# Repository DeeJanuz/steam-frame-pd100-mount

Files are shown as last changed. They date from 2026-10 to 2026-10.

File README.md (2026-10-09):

# Steam Frame PD100 Mount

3D-printable mounts that hold a BoboVR PD100 (the PD100 dock with a B100 battery) on the rear battery pod of a Valve Steam Frame. Each mount slides onto a dovetail key on a clip that wraps around the pod and leaves room for the rear cushion:

- **Under mount:** hangs the PD100 below and behind the pod. It suits fast-paced games, since there is less movement low on the head.
- **Over mount:** lays the PD100 over the top of the pod at a flat angle. Very little sticks out behind your head, so you can lean back against a headrest.

| Under mount | Over mount |
|---|---|
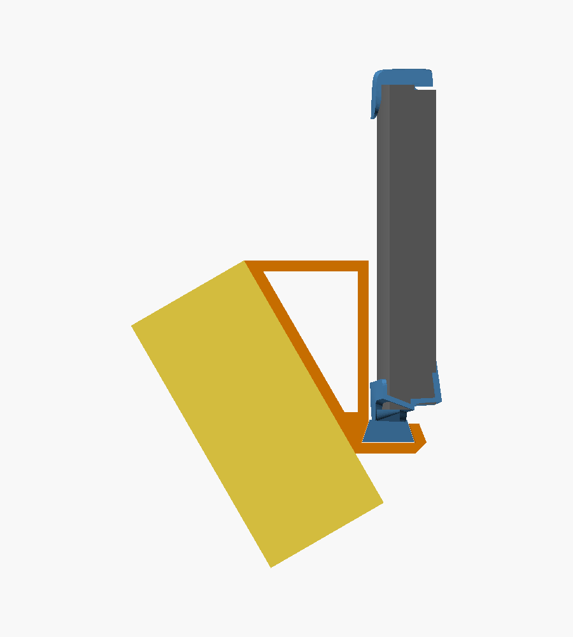
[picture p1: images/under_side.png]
Under mount, section through the middle of the pod with the head to the right
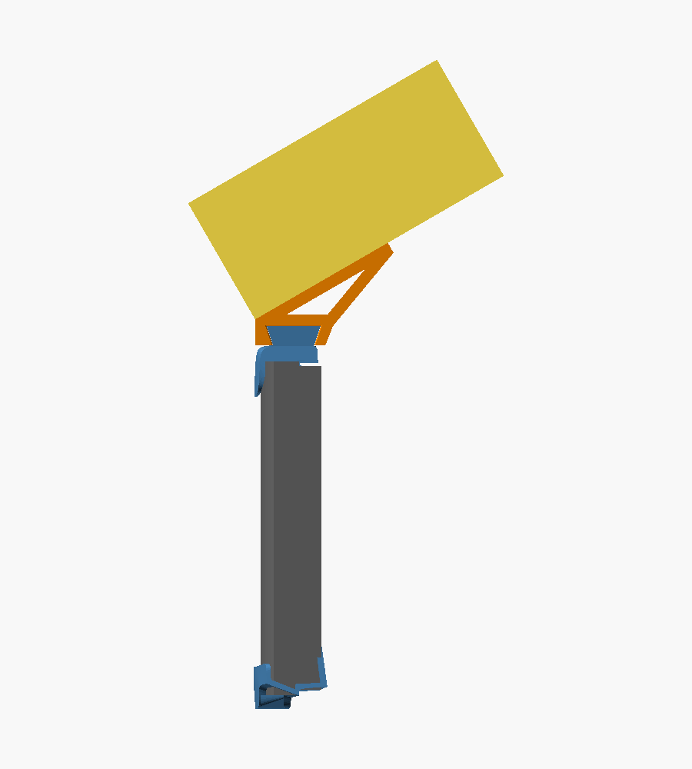
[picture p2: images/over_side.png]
Over mount, section through the middle of the pod with the head to the right
|  |  |

Sections through the middle of the pod, with the head to the right. The pod is gray, the clip is blue, the mount is orange, and the PD100 is shown as a yellow block. The clip is drawn as printed, so its spine overlaps the pod.

## How the clip works

The clip is a remix of [SpanishPotato's Steam Frame back clip](https://www.patreon.com/SpanishPotato/posts/steam-frame-back-171534740), whose file is in `cad/ref/SteamFrameBackClip.stl`. Only its attachment is changed: its two slots are filled in, and our 30 mm dovetail key takes the place of one of them. Everything else is as in that file:

- A cap with a long lip hooks over the pod's top edge.
- A thin spine runs down the side of the pod that faces your head. It has two windows, and a slit under the cap lets it flex.
- At the bottom, a block with a short lip hooks only the outer shell's bottom edge. Legs at the clip's ends join it to the spine. In the middle, the head side of the pod's bottom edge stays free, so the rear cushion can go back on.
- Three small pegs face the pod from the spine and legs.

There are four versions. `clip_over` has the key on top of the cap for the over mount, and `clip_under` has it under the bottom block for the under mount. Each mount slides onto its key from the side.

The other two are versions of `clip_over` with a different outline, for an over mount that rocks less. Seen from the head side, the original is a trapezoid: about 32 mm wide at the cap and 59 mm wide at the bottom. Both versions have a cap 59 to 60 mm wide and a 55 mm key, the full width of the over mount. At every height, the cross-section is the same as the original's, so the cap, lips, slit, and bottom block grip the pod in the same way. `cad/ref/reshape.py` makes these changes.

- `clip_over_straight` is 59 mm wide from top to bottom. Its bottom is the original's, so the cushion fits the same way as with `clip_over`.
- `clip_over_wide` is the original turned upside down: 60 mm wide at the cap and about 32 mm at the bottom. The narrow bottom brings the legs and end bars in to about 10 to 16 mm from the middle. In `clip_over`, that part of the pod's bottom edge on the head side stays free for the cushion, so the cushion may not go back on with `clip_over_wide`. The two small pegs at the bottom also move in, from about 22 mm to 13 mm out.

## What you need

- A Valve Steam Frame.
- A [BoboVR PD100 charging dock](https://www.amazon.com/dp/B0FLXQMPCS). This listing is the dock only, without a battery.
- A B100-style battery for the dock, such as this [DMMNS 10000 mAh two-pack](https://www.amazon.com/dp/B0FHK169RV), which is sold as a replacement for the BoboVR B100.
- 3M Command strips to hold the PD100 on the mount.

## Parts

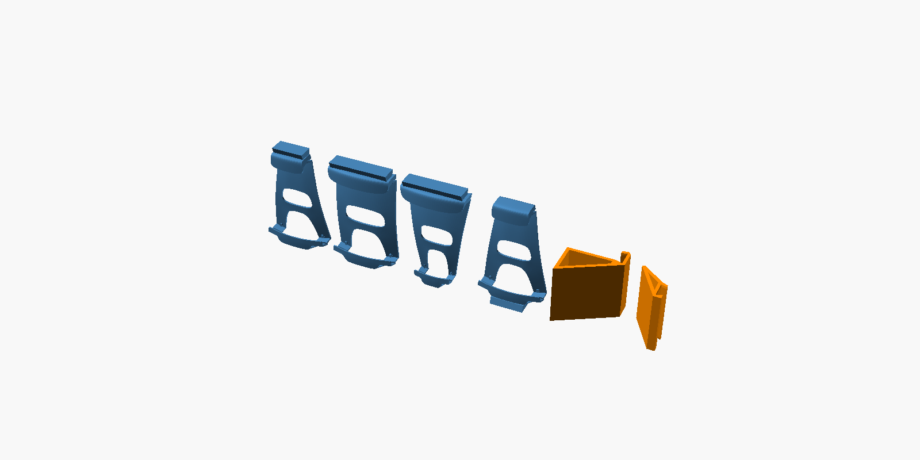
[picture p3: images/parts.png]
The four clips and both mounts, as they sit on the print bed


| File | Quantity | Notes |
|---|---|---|
| `stl/clip_under.stl` | 1 | Clip with the key underneath, for the under setup |
| `stl/clip_over.stl` | 1 | Clip with the key on top, for the over setup |
| `stl/clip_over_straight.stl` | 1 | Instead of `clip_over`: 59 mm wide at the top and bottom, so the over mount rocks less |
| `stl/clip_over_wide.stl` | 1 | Instead of `clip_over`: wide at the top and narrow at the bottom, so the over mount rocks less |
| `stl/under_mount.stl` | 1 | For the under setup |
| `stl/over_mount.stl` | 1 | For the over setup |

Print the clip and mount for the setup you want, or both pairs.

## Printing

- The STL files are already oriented.
- The clips print upright like the original file, 100 mm tall: `clip_over`, `clip_over_straight`, and `clip_over_wide` stand on the bottom block and `clip_under` on its key. `clip_over_wide` stands on a block only about 15 mm wide under a 60 mm cap, so use a brim. They need supports under the end bars at the bottom, under the tip of the long lip, and under the cap. If supports end up in the slit under the cap, clear them out completely, since the spine flexes there.
- The mounts print on their side with no supports, 55 mm tall, so the layers run in the direction that carries the battery's weight.
- PETG is recommended. PLA can soften over time from body heat and a warm battery.
- As solid plastic, `clip_over` and `clip_under` are about 11.5 cm³ each, `clip_over_wide` about 15 cm³, `clip_over_straight` about 17 cm³, the under mount about 26 cm³, and the over mount about 14 cm³. Your slicer will report the actual weight for your infill.

## Assembly

### Fitting the clip

1. With the spine against the side of the pod that faces your head, hook the cap's long lip over the pod's top edge.
2. Press the bottom of the clip toward the pod until the short lip snaps over the outer shell's bottom edge.
3. Center the clip on the pod.

### Under setup

1. Fit `clip_under`.
2. Slide the under mount onto the key under the clip from one side until it is centered. Its upper part sits just behind the pod's outer shell.
3. Stick the PD100 to the mount's angled face with 3M Command strips. The PD100's flat bottom goes against the mount, with the display edge toward the pod.

### Over setup

1. Fit `clip_over`, `clip_over_straight`, or `clip_over_wide`.
2. Slide the over mount onto the key on top of the clip from one side until it is centered. On `clip_over_straight` and `clip_over_wide`, the key runs the mount's full width.
3. Stick the PD100 to the platform with Command strips, with its display edge at the back of the platform.

The dovetail fit is tight on purpose so the mount stays put by friction. If a mount will not slide on, lightly sand the sides of the key, or increase `dt_gap` in `cad/common.scad` and reprint the mount.

## Fit and customizing

The clip's fit is the original file's and has not been changed. The pod measurements come from calipers on one Steam Frame and place the mounts and the assembly views. The main numbers:

- The pod's outer shell is 87.0 mm tall at the seam, and the part that faces your head is 84.5 mm tall.
- The pod is 12.0 mm thick at the middle of its top and bottom edges, and the outer shell is about 6.5 mm of that.
- The outer shell bulges about 1.6 mm at mid-height.
- Seen from above, the pod curves with a radius of about 117.5 mm.

The design is written in OpenSCAD. Settings you are most likely to change:

| File | Setting | What it does |
|---|---|---|
| `cad/pod_dims.scad` | all values | Pod measurements |
| `cad/common.scad` | `curve_radius` | Curve of the pod seen from above |
| `cad/common.scad` | `dt_gap` | Dovetail clearance per face |
| `cad/common.scad` | `mount_width` | Mount width (55 mm by default) |
| `cad/common.scad` | `key_len` | Length of the key on `clip_over` and `clip_under` (30 mm by default) |
| `cad/common.scad` | `key_len_wide` | Length of the key on `clip_over_straight` and `clip_over_wide` (the mount's width by default) |
| `cad/under.scad` | `under_tilt` | Angle of the under mount's face, from vertical (30 by default) |
| `cad/under.scad` | `corner_below` | How far below the pod the PD100's front corner may reach. This is the part that can touch your neck when you look up. |
| `cad/over.scad` | `over_tilt` | Angle of the over mount's platform, from vertical (60 by default) |
| `cad/over.scad` | `platform_len` | Platform length from its back end to the tip (40 mm by default) |
| `cad/over.scad` | `back_reach` | Moves the PD100 back and down along the platform, away from your head (0 by default) |

## Building the STL files

Use a recent OpenSCAD development snapshot. From the repository folder:

```sh
openscad -D 'part="clip_under"'  -D print=true -o stl/clip_under.stl  cad/clip.scad
openscad -D 'part="clip_over"'   -D print=true -o stl/clip_over.stl   cad/clip.scad
openscad -D 'part="clip_over_straight"' -D print=true -o stl/clip_over_straight.stl cad/clip.scad
openscad -D 'part="clip_over_wide"' -D print=true -o stl/clip_over_wide.stl cad/clip.scad
openscad -D 'part="under_mount"' -D print=true -o stl/under_mount.stl cad/under.scad
openscad -D 'part="over_mount"'  -D print=true -o stl/over_mount.stl  cad/over.scad
```

`clip_over_straight` and `clip_over_wide` are built from `cad/ref/SteamFrameBackClip_straight.stl` and `cad/ref/SteamFrameBackClip_wide_top.stl`. Those files only need rebuilding if you change how the original's slots are filled or the pod's curve. Rebuilding them takes Python with numpy, trimesh, and manifold3d:

```sh
openscad -D 'part="clip_filled"' -o /tmp/clip_filled.stl cad/clip.scad
python cad/ref/reshape.py straight /tmp/clip_filled.stl cad/ref/SteamFrameBackClip_straight.stl
python cad/ref/reshape.py wide_top /tmp/clip_filled.stl cad/ref/SteamFrameBackClip_wide_top.stl
```

Opening `cad/under.scad` or `cad/over.scad` in OpenSCAD without any settings shows the assembly with the pod and a block the size of the PD100. Opening `cad/clip.scad` shows the clip on the pod with both keys.

## Disclaimer

This project is not affiliated with Valve or BoboVR. It holds a lithium battery on your head, so check the fit and the Command strips before each session, and stop using it if anything cracks or loosens.

## License

MIT. See [LICENSE](LICENSE). The MIT license does not cover SpanishPotato's clip: `cad/ref/SteamFrameBackClip.stl`, `cad/ref/SteamFrameBackClip_straight.stl`, `cad/ref/SteamFrameBackClip_wide_top.stl`, and the clip STLs built from them (`stl/clip_over.stl`, `stl/clip_over_straight.stl`, `stl/clip_over_wide.stl`, and `stl/clip_under.stl`). See the [original post](https://www.patreon.com/SpanishPotato/posts/steam-frame-back-171534740) for its terms.

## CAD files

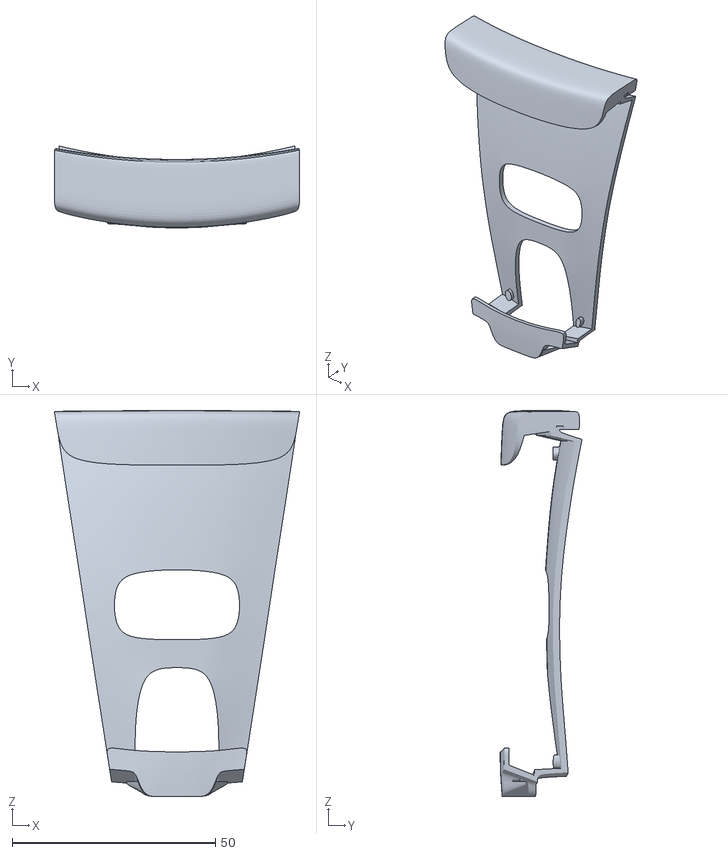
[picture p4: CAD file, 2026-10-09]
cad/ref/SteamFrameBackClip_wide_top.stl
60.4 x 20.2 x 95.1

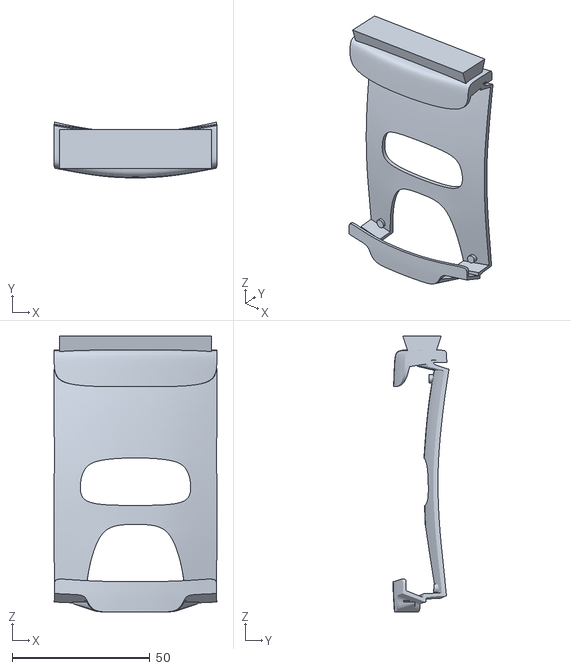
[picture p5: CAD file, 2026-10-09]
stl/clip_over_straight.stl
59.0 x 20.3 x 100.0

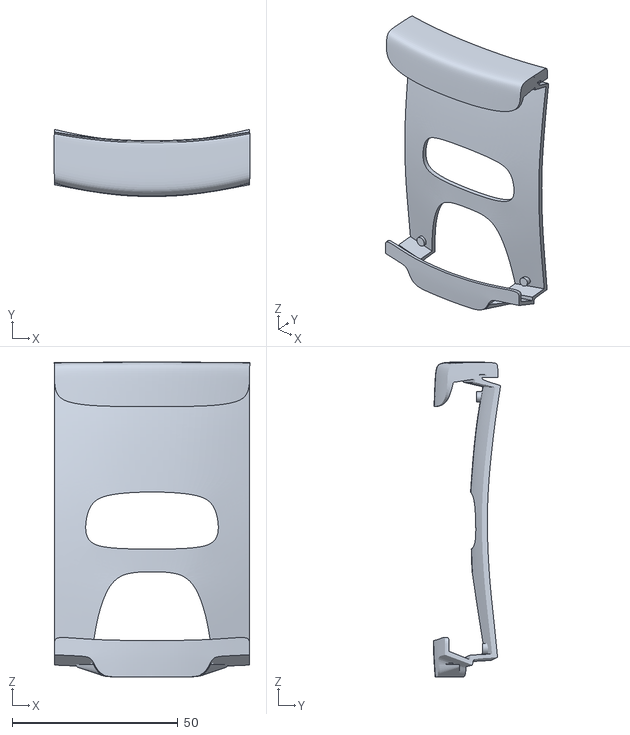
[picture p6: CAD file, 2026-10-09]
cad/ref/SteamFrameBackClip_straight.stl
59.0 x 20.3 x 95.1

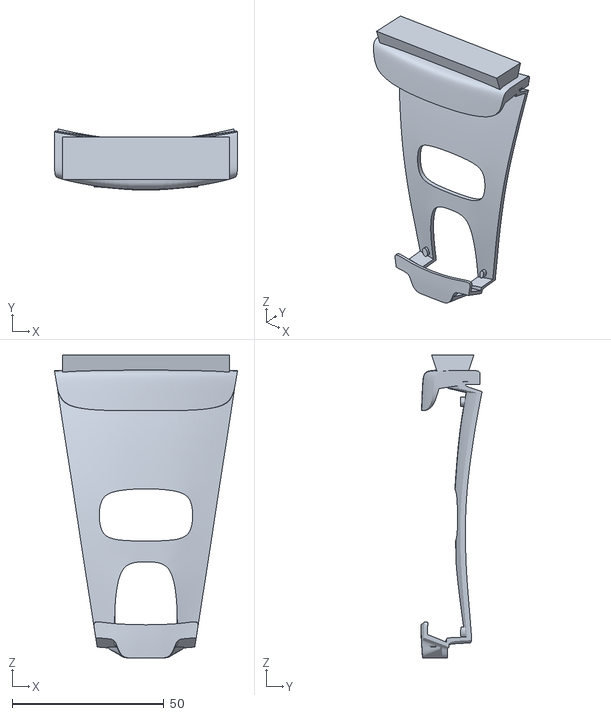
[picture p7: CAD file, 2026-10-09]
stl/clip_over_wide.stl
60.4 x 20.2 x 100.0

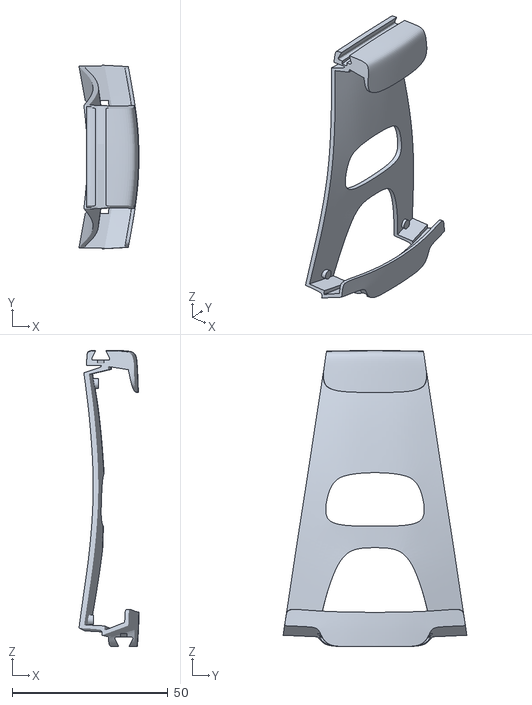
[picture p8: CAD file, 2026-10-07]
cad/ref/SteamFrameBackClip.stl
19.3 x 59.0 x 95.1

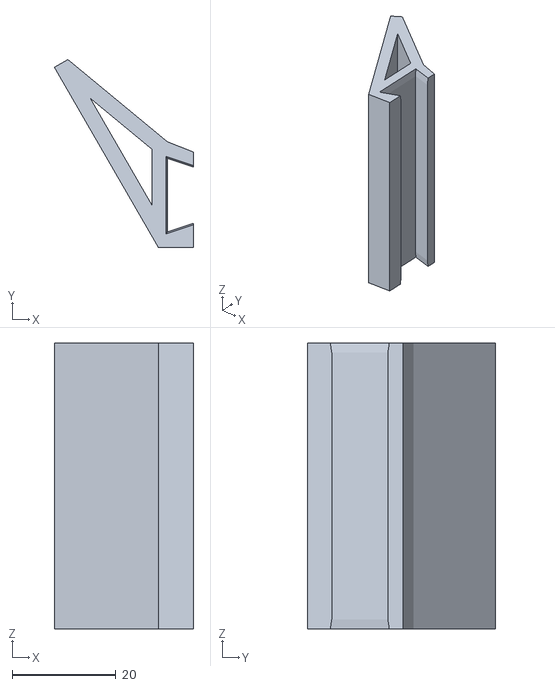
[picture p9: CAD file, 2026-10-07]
stl/over_mount.stl
26.8 x 36.1 x 55.0

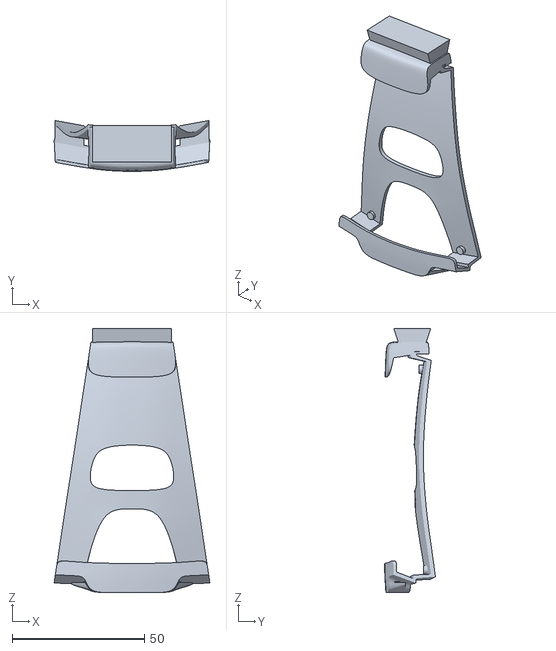
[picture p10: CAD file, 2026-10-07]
stl/clip_over.stl
59.0 x 19.3 x 100.0

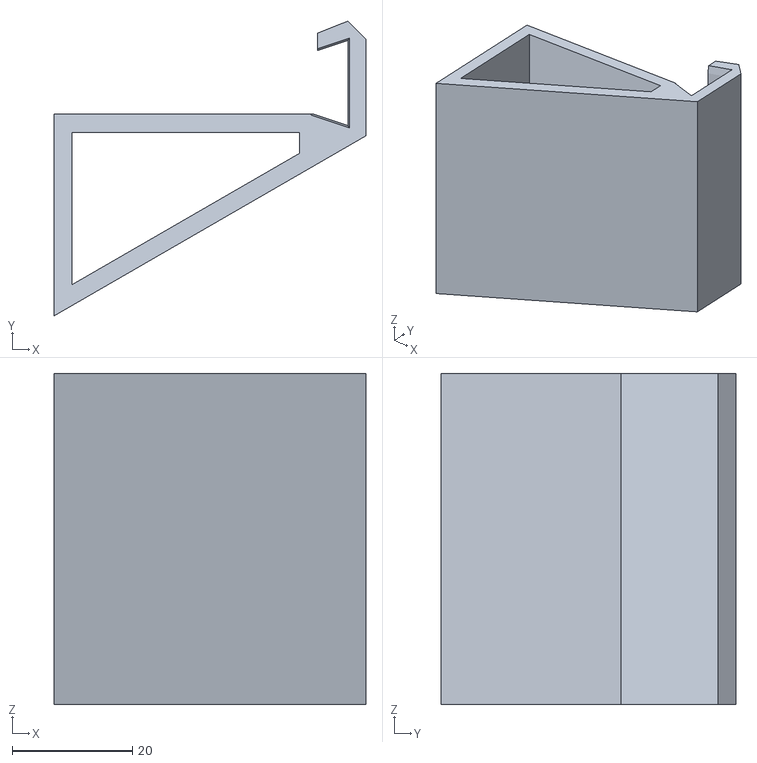
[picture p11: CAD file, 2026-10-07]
stl/under_mount.stl
51.8 x 49.0 x 55.0

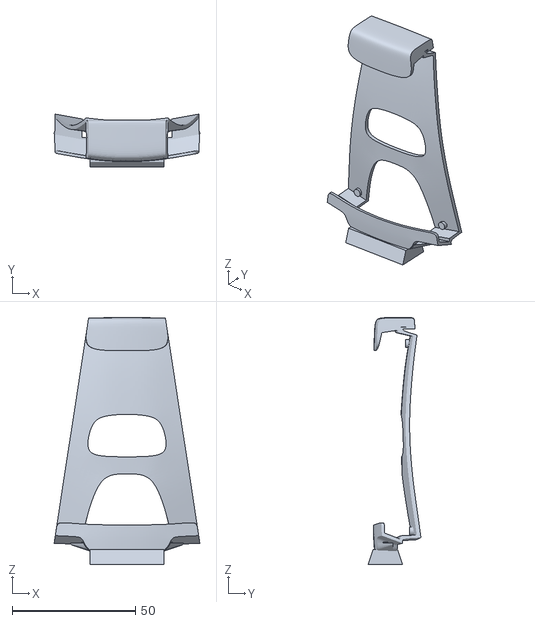
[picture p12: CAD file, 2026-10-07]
stl/clip_under.stl
59.0 x 21.4 x 100.1

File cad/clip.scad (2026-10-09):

// The clip that holds either mount on the Steam Frame's battery pod. It is
// SpanishPotato's Steam Frame back clip
// (https://www.patreon.com/SpanishPotato/posts/steam-frame-back-171534740)
// with its two slots filled and our dovetail key added in place of one of
// them: on top of the cap for the over mount, or under the bottom block for
// the under mount. Everything else is the original: the cap and its long lip
// over the pod's top edge, the slit under the cap that lets the spine flex,
// the spine on the head side with its two windows, the pegs, and the bottom
// block and short lip, which leave the head side of the pod's bottom edge
// free for the cushion. ref/SteamFrameBackClip.stl is that file merged into
// one solid. Not covered by this project's MIT license. Axes as in
// pod_dims.scad.
include <common.scad>

part = "clip_assembly";  // clip_assembly, clip_over, clip_under, clip_over_wide, clip_over_straight

// clip_over has only the key on top, for the over mount; clip_under has only
// the key underneath, for the under mount. Both print upright like the
// original, standing on the bottom block or the bottom key.
// key_bot[1] is the height of the bottom block's underside.
if (part == "clip_over") translate([0, 0, print ? -key_bot[1] : 0]) clip(bottom = false);
if (part == "clip_under") translate([0, 0, print ? dt_height - key_bot[1] : 0]) clip(top = false);
// clip_over_wide and clip_over_straight have a cap as wide as the original's
// bottom and a 55 mm key, so the over mount rocks less (see ref/reshape.py).
// clip_over_wide is clip_over upside down in outline: its bottom is as narrow
// as the original's cap, so its legs come in over the middle of the pod's
// bottom edge, where clip_over leaves room for the cushion. clip_over_straight
// keeps the original's bottom.
if (part == "clip_over_wide") translate([0, 0, print ? -key_bot[1] : 0]) clip_reshaped(clip_wide_file);
if (part == "clip_over_straight") translate([0, 0, print ? -key_bot[1] : 0]) clip_reshaped(clip_straight_file);
// Both slots filled and no key: the input to ref/reshape.py.
if (part == "clip_filled") clip(top = false, bottom = false);
if (part == "clip_assembly") {
    color("dimgray") pod();
    color("steelblue") clip();
}

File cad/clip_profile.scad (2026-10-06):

// Cross-section of the clip, in the (Y, Z) plane; see pod_dims.scad.
// The clip wraps the whole pod: a thin spine lies on the head-side face, bars
// cross the top and bottom edges, and short lips reach over the outer face.
// Each bar steps down behind the outer shell's rim to fill the ledge at the seam.
//
// As printed, the spine bows toward the pod, which splays the bars open so
// the lips pass over the pod's edges. On the pod, the head-side face presses
// the spine flat. That closes the bars and keeps the lips pressed on the
// outer face, so the clip does not rattle.
include <pod_dims.scad>

spine_gap     = 0.2;    // spine to the head-side face, once pressed flat
spine_thick   = 2.0;
spine_bow     = 3.0;    // as printed, how far the spine bows toward the pod at mid-height
bar_thick     = 3.0;    // over the outer shell's rim
lip_thick     = 1.6;
lip_len       = 4.0;    // how far each lip reaches down the outer face
lip_ramp      = 1.0;    // lead-in at each lip's tip
step_gap_y    = 0.35;   // a bar's step to the back of the outer shell
step_gap_z    = 0.25;   // a bar to the top of the head-side part
inner_chamfer = 1.0;    // inside corner where the spine meets a bar
edge_chamfer  = 1.0;    // outside corners

// Underside of a bar over the outer shell, for a given rim clearance.
function z_bar(clearance) = shell_height / 2 + clearance;
// Outer face, modeled as a parabola from the edges (Y = 0) to the bulge at mid-height.
function outer_y(z) = -outer_bulge * (1 - pow(z / (shell_height / 2), 2));

y_spine_in  = total_thick_edge + spine_gap;
y_spine_out = y_spine_in + spine_thick;
y_step      = max(shell_thick_top, shell_thick_bottom) + step_gap_y;
z_head      = head_part_height / 2 + step_gap_z;

// Where the spine meets a bar. With the spine bowed, each bar turns about this
// point by bow_angle, the slope at the end of the bowed spine.
pivot = [y_spine_in + spine_thick / 2, z_head - inner_chamfer];
function bow_angle(bow) = atan(2 * bow / pivot[1]);

// Back of a lip at its tip, with the spine flat. The lips lean out to follow
// the bulge, so this is the rearmost point of the clip.
function lip_back_y(clearance) = outer_y(z_bar(clearance) - lip_len) - lip_thick;

// Top bar and lip with the spine flat, from the pivot's height up.
module bar_2d(clearance) {
    zr = z_bar(clearance);
    zt = zr + bar_thick;
    z_tip = zr - lip_len;
    y_tip = outer_y(z_tip);
    polygon([[y_spine_in, pivot[1] - 0.3],
             [y_spine_in, z_head - inner_chamfer],
             [y_spine_in - inner_chamfer, z_head],
             [y_step, z_head],
             [y_step, zr],
             [0, zr],
             [y_tip, z_tip + lip_ramp],
             [y_tip - lip_ramp, z_tip],
             [y_tip - lip_thick, z_tip],
             [-lip_thick, zt - edge_chamfer],
             [-lip_thick + edge_chamfer, zt],
             [y_spine_out - edge_chamfer, zt],
             [y_spine_out, zt - edge_chamfer],
             [y_spine_out, pivot[1] - 0.3]]);
}

// Upper half of the spine, bowed into a parabola that is flat at mid-height
// and reaches the pivot at bow_angle. Offsets are normal to the centerline, so
// the end matches the turned bar.
module spine_half_2d(bow) {
    n = 24;
    zp = pivot[1];
    function ctr(z) = pivot[0] - bow * (1 - pow(z / zp, 2));
    function nrm(z) = let(s = 2 * bow * z / (zp * zp)) [1, -s] / sqrt(1 + s * s);
    zs = [for (i = [0 : n]) -0.5 + (zp + 0.3 + 0.5) * i / n];
    polygon(concat([for (z = zs) [ctr(z), z] - spine_thick / 2 * nrm(z)],
                   [for (i = [n : -1 : 0]) [ctr(zs[i]), zs[i]] + spine_thick / 2 * nrm(zs[i])]));
}

// Turn 2D children about the pivot by the bow's angle, opening the bar.
module turn_bar(bow) {
    translate(pivot) rotate(-bow_angle(bow)) translate(-pivot) children();
}

// Top half. The bottom half is this mirrored.
module clip_half_2d(clearance, bow) {
    spine_half_2d(bow);
    turn_bar(bow) bar_2d(clearance);
}

// The clip's cross-section: bowed as printed (bow = spine_bow), or pressed flat
// on the pod (bow = 0).
module clip_2d(clearance, bow) {
    clip_half_2d(clearance, bow);
    mirror([0, 1]) clip_half_2d(clearance, bow);
}

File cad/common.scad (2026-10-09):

// Shared settings and helpers for the Steam Frame PD100 mounts. Every mount
// prints on its side, so the layers lie in the plane that carries the PD100's
// weight. Axes as in pod_dims.scad.
include <pod_dims.scad>

part     = "none";
explode  = 0;          // assembly views: slide the mount out along X
print    = false;      // true: turn the chosen part to its print orientation
pod_view = pod_width;  // assembly views: how much of the pod's width to draw

curve_radius  = 117.5;  // pod's curve seen from above (between the R110 and R125 test gauges)

// BoboVR PD100 combo (dock + B100 battery), from the Amazon listing.
pd_across = 113;  // left to right, same direction as the pod
pd_up     = 75;   // along the mount's face
pd_thick  = 35;

mount_width = 55;
mount_wall  = 3;      // material around the groove in a mount
plate_thick = 3;      // platform thickness at its tip

dt_root    = 10;      // dovetail key width at its base
dt_tip     = 14;      // key width at its top
dt_height  = 5;
dt_gap     = 0.05;    // clearance per face in a mount's groove; starts tight, open up if needed
dt_lead_in = 2;       // groove flares open over this length at each end of a mount

// The clip is ref/SteamFrameBackClip.stl with its two slots replaced by our
// key. In that file X runs through the pod from the head side, Y across it,
// and Z up. These place it on the pod:
clip_file = "ref/SteamFrameBackClip.stl";
clip_mid  = 29.5;    // file Y at the clip's middle
clip_y0   = 17.4;    // file X of the top lip's inner face, which sits on the pod's outer face
clip_z0   = 47.3;    // file Z halfway between the cap and the bottom block, at the seam
clip_back_y = clip_y0 - 19.31;   // rearmost point of the clip: the lips at its middle

// Keys, as [Y of the centerline, Z of the base]: one on top of the cap for the
// over mount and one under the bottom block for the under mount, each where
// the file has its slot. Both run straight along X, key_len long.
key_len = 30;
key_top = [clip_y0 - 8.8,   95.0 - clip_z0];   // points up
key_bot = [clip_y0 - 14.42, 0 - clip_z0];      // points down

// The file's slots, in its (X, Z) plane with some overlap into the walls.
top_slot = [[4.0, 91.3], [10.0, 91.3], [10.0, 95.2], [4.0, 95.2]];
bot_slot = [[11.4, 0.01], [17.4, 0.01], [17.4, 3.7], [11.4, 3.7]];   // stops just above the block's underside, which a fill flush with it would leave non-manifold

// The groove's outer wall leans with the dovetail's flank.
flank_dy = (dt_tip - dt_root) / 2;
// Front of a mount (toward the head) at the key's base and at its tip.
function y_front_base(key) = key[0] + dt_root / 2 + dt_gap + mount_wall * sqrt(1 + (flank_dy / dt_height) ^ 2);
function y_front_tip(key)  = y_front_base(key) + flank_dy;
// Rear of a mount, level with the key's tip.
function y_rear_tip(key)   = key[0] - dt_tip / 2 - dt_gap - mount_wall;

// Extrude a (Y, Z) profile along X, centered.
module extrude_x(len) {
    translate([-len / 2, 0, 0]) rotate([90, 0, 90]) linear_extrude(len) children();
}

// Sweep a (Y, Z) profile along the pod's curve, keeping x_lo <= X <= x_hi.
module swept(x_lo, x_hi) {
    reach = max(abs(x_lo), abs(x_hi)) + 2;
    ang = 2 * asin(min(0.99, reach / (curve_radius - 15)));
    intersection() {
        translate([0, curve_radius, 0]) rotate(-90 - ang / 2)
            rotate_extrude(angle = ang, $fn = 720)
                translate([curve_radius, 0]) mirror([1, 0]) children();
        translate([x_lo, -500, -500]) cube([x_hi - x_lo, 1000, 1000]);
    }
}

// Male dovetail with its base on the X axis, pointing +Y. The base runs 1 mm
// below the axis so it stays buried in the part it stands on.
module rail_2d() {
    polygon([[-dt_root / 2, -1], [dt_root / 2, -1],
             [dt_tip / 2, dt_height], [-dt_tip / 2, dt_height]]);
}

// Matching groove with clearance g on every face, open below the X axis.
module groove_2d(g) {
    offset(delta = g) rail_2d();
    translate([-dt_root / 2 - g, -1]) square([dt_root + 2 * g, 1]);
}

// Place 2D children at point q, rotated so +Y points along dir.
module at(q, dir) {
    translate(q) rotate(atan2(dir[1], dir[0]) - 90) children();
}

// Move children from the clip file's axes onto the pod.
module clip_file_to_pod() {
    rotate([0, 0, -90]) translate([-clip_y0, -clip_mid, -clip_z0]) children();
}

// Fill a slot, given in the file's (X, Z) plane, over the length of the part
// around it: everything in the file inside box, closed up.
module fill_slot(slot, box) {
    intersection() {
        translate([0, 70, 0]) rotate([90, 0, 0]) linear_extrude(80) polygon(slot);
        hull() intersection() {
            import(clip_file);
            translate(box[0]) cube(box[1]);
        }
    }
}

// The clip on the pod, with both slots filled and a key on top of the cap
// (top), under the bottom block (bottom), or both.
module clip(top = true, bottom = true) {
    clip_file_to_pod() {
        import(clip_file);
        fill_slot(top_slot, [[0, 0, 91.3], [20, 60, 5]]);
        fill_slot(bot_slot, [[9, 0, -1], [11, 60, 4.7]]);
    }
    extrude_x(key_len) {
        if (top) at(key_top, [0, 1]) rail_2d();
        if (bottom) at(key_bot, [0, -1]) rail_2d();
    }
}

// The same clip with its outline changed by ref/reshape.py, as seen from the
// head side. wide_top is upside down: as wide at the cap as the original is at
// the bottom, and as narrow at the bottom as the original's cap. straight is
// as wide as the original's bottom all the way up. The files are in pod axes
// with both slots already filled. Their wide caps carry a key as long as the
// mount.
clip_wide_file     = "ref/SteamFrameBackClip_wide_top.stl";
clip_straight_file = "ref/SteamFrameBackClip_straight.stl";
key_len_wide       = mount_width;

module clip_reshaped(file) {
    import(file);
    extrude_x(key_len_wide) at(key_top, [0, 1]) rail_2d();
}

// Extrude a mount's (Y, Z) profile along X and cut the groove for a key at
// [Y, Z of its base] that points up (s = 1) or down (s = -1). The groove
// flares at both ends so the tight fit starts onto the key easily.
module mount_body(key, s) {
    difference() {
        extrude_x(mount_width) difference() {
            children();
            at(key, [0, s]) groove_2d(dt_gap);
        }
        for (m = [0, 1]) mirror([m, 0, 0])
            translate([mount_width / 2 - dt_lead_in, key[0], key[1]]) rotate([90, 0, 90])
                linear_extrude(dt_lead_in + 0.01, scale = 1.06)
                    rotate(s > 0 ? 0 : 180) groove_2d(dt_gap - 0.02);
    }
}

// Pod outline for the assembly views: outer shell and head-side part, swept.
module pod() {
    swept(-pod_view / 2, pod_view / 2) {
        translate([0, -shell_height / 2]) square([shell_thick_top, shell_height]);
        translate([shell_thick_top, -head_part_height / 2])
            square([total_thick_edge - shell_thick_top, head_part_height]);
    }
}

// Lay a part on its side, lowest X face (x_lo) on the bed.
module on_side(x_lo) {
    if (print) translate([0, 0, -x_lo]) rotate([0, -90, 0]) children();
    else children();
}

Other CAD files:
cad/over.scad
cad/pod_dims.scad
cad/under.scad

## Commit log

2026-09-28 Add under and over PD100 mounts for the Steam Frame
    Clip-on arms snap over the Steam Frame's rear battery pod and carry a
    dovetail rail across their backs. Two mounts slide onto those rails:
    - The under mount hangs the BoboVR PD100 below and behind the pod at
    30 degrees, keeping its front corner 25 mm below the pod so it clears
    the neck.
    - The over mount uses the same arms turned upside down and lays the
    PD100 over the top on a 40 mm platform at 60 degrees, so little
    sticks out behind the head.
    Includes the OpenSCAD source, print-ready STLs, and README images.
    [common.scad, hook_profile.scad, over.scad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]
2026-09-28 Remove the assembly image from the README
2026-10-06 Replace the clip-on arms with a wrap-around clip
    One clip now wraps the whole pod: a 2 mm spine lies on the side that faces
    the head, bars cross the top and bottom edges, and short lips hook over the
    outer shell. The dovetail rail moves from the back of the pod to the clip's
    top bar, and the clip is worn upside down for the under setup.
    The spine prints bowed toward the pod so the bars spread open to fit. On the
    pod the spine is pressed flat, which closes the bars and preloads the lips.
    Both mounts are redesigned for the new rail and hollowed into trusses. The
    over mount now puts the PD100 12.7 mm less far behind the pod. Adds a 10 mm
    clip_test slice for checking the fit before printing th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
    [clip.scad, clip.stl, clip_profile.scad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]
2026-10-06 Split the wrap-around clip into two clip-on arms
    Each arm is 15 mm wide and sits about 18 mm either side of the pod's
    center, like the original arms, but wraps the pod from the head side with
    the same bowed spine and short lips as the one-piece clip. Each arm carries
    a rail segment on its top bar, and both segments share one line so the
    mounts slide across them. The arms are mirror images and swap sides when
    worn upside down for the under setup.
    The pair uses 10.7 cm3 of plastic against 17.7 cm3 for the one-piece clip.
    The test slice is dropped, since one arm is cheap enough to test-print.
    [arm_left.stl, arm_profile.scad, arm_right.stl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]
2026-10-06 Use a thinner, more bowed spine and uneven lips on the arms
    The spine is now 1.65 mm thick and bowed 3.6 mm as printed. The bar that
    carries the rail gets a 7.5 mm lip that tapers from 1.4 to 0.7 mm and leans
    out 1 mm at its tip; the other bar gets a straight 3.8 mm lip. The long lip
    hooks on first and the short lip snaps on last.
    Each bar now sits 1.2 mm into the pod's edge (rim_clearance = -1.2), so the
    arms squeeze the pod instead of fitting it exactly. rim_clearance moves to
    arm_profile.scad and also applies to the step over the head-side part.
    [arm_left.stl, arm_profile.scad, arm_right.stl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]
2026-10-07 Tighten the arms by 2 mm and lengthen the short lip
    Test prints at -2, -4 and -6 mm showed the arms at rim_clearance -1.2 were
    loose and that 2 mm smaller fits well, so rim_clearance is now -2.2. The
    short lip grows from 3.8 to 5.0 mm because the arms slipped off too easily.
    Adds fit_offset for building test arms in other sizes. A nonzero offset is
    split between the two bars and engraved on top of the rail. The mounts are
    rebuilt for the lower rails.
    [arm_left.stl, arm_profile.scad, arm_right.stl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]
2026-10-07 Replace the arms with SpanishPotato's back clip, keyed for our mounts
    The wrap-around arms covered the head side of the pod's bottom edge, so the
    rear cushion could not go back on. The clip is now a remix of SpanishPotato's
    Steam Frame back clip, whose bottom block hooks only the outer shell and
    leaves that edge free. Its two slots are filled and our 30 mm dovetail key
    takes the place of one: on top of the cap (clip_over) or under the bottom
    block (clip_under). The rest of the original is unchanged.
    cad/ref/SteamFrameBackClip.stl is the original file merged into one solid.
    It and the clip STLs are not covered by the MIT license; the README credits
    and links the original.
    The mounts now tak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
    [SteamFrameBackClip.stl, arm_left.stl, arm_profile.scad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]
2026-10-09 Add two over clips with a wide cap: straight and wide-top
    The over mount rocked forward and back on clip_over's 32 mm cap. Two new
    versions widen the cap to 59-60 mm and carry a 55 mm key, the over mount's
    full width:
    - clip_over_straight is 59 mm wide from top to bottom. Its bottom is the
    original's, so the cushion fits as with clip_over.
    - clip_over_wide turns the original's outline upside down: wide at the cap,
    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
    [SteamFrameBackClip_straight.stl, SteamFrameBackClip_wide_top.stl, clip.scad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]
